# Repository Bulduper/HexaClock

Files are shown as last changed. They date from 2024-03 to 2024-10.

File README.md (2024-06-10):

# 	&#11042;	 HexaClock
<p align="center">
  
</p>

### Welcome to the repository made to share my awesome project with the world.

The *Hexa Clock* is a hexagon-shaped LED matrix with each pixel also in the shape of a hexagon!
There are 127 individual RGB pixels ready to pour some colors on your wall.

The project is based on an awesome and popular [WLED by Aircookie](https://github.com/Aircoookie/WLED) project (software-wise). I created a usermod to adjust WLED for my weirdly shaped matrix and to display the time.

All the hardware was designed, produced and assembled by me.
## 🎉Features
- Night mode - It doesn't let your eyes get tired in the night... unless you wanna throw a 🎵🕺party🕺🎵 - then better keep the night mode off, let the 🎨 colors fill the room!
- Auto-brightness - It detects the ambient light level and auto-adjusts its brightness.



- Multiple presets - the effects run one after another in a loop. To make it even more interesting they can run in random order 😀

<p float="left">
  
  
  
  
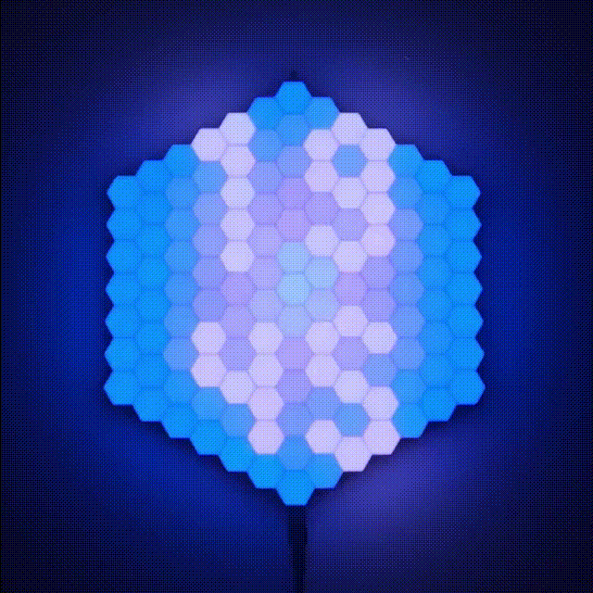
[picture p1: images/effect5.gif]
  
and more...
</p>

- Web app to control the effects
  
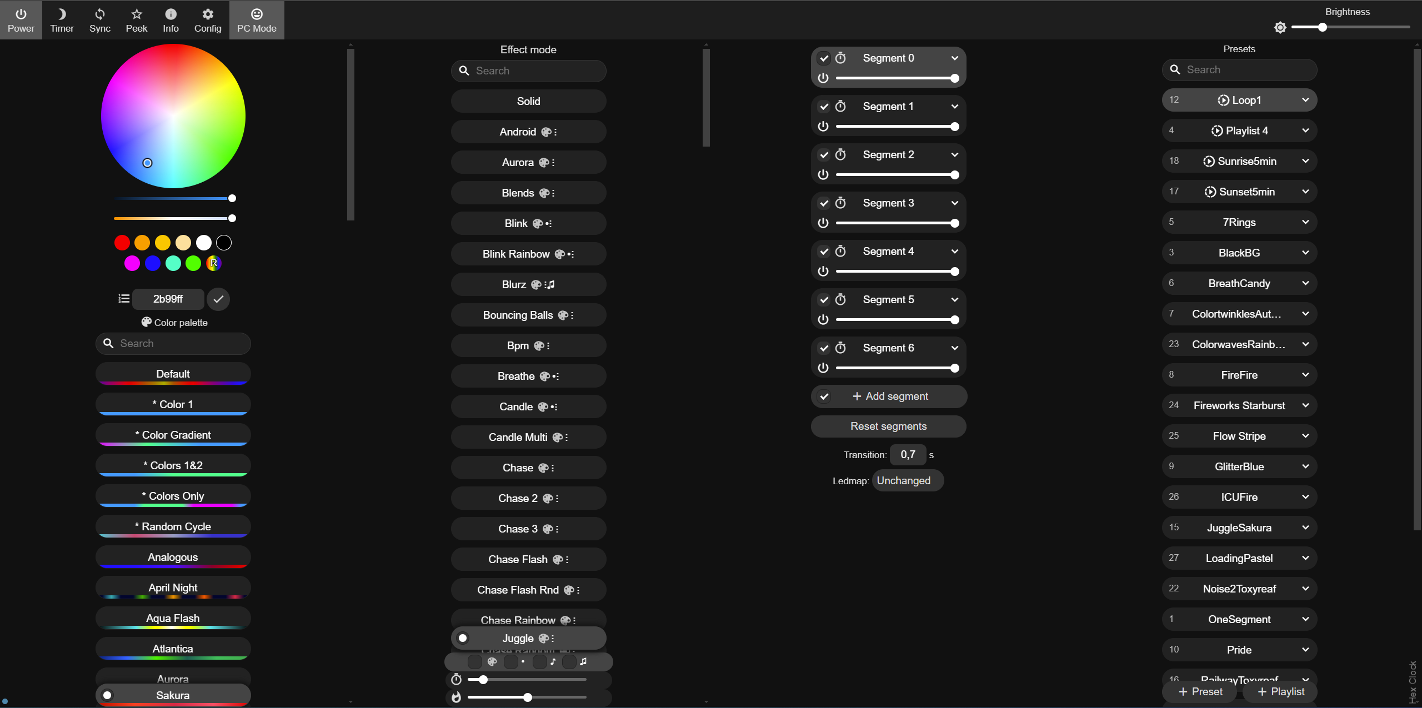
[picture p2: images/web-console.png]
  
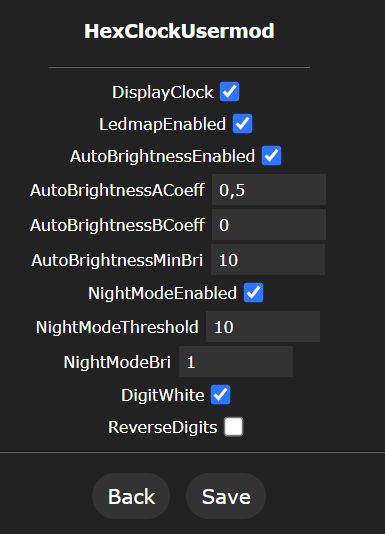
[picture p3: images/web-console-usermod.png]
  

- 🌅sunrise & sunset effects - A special effect plays

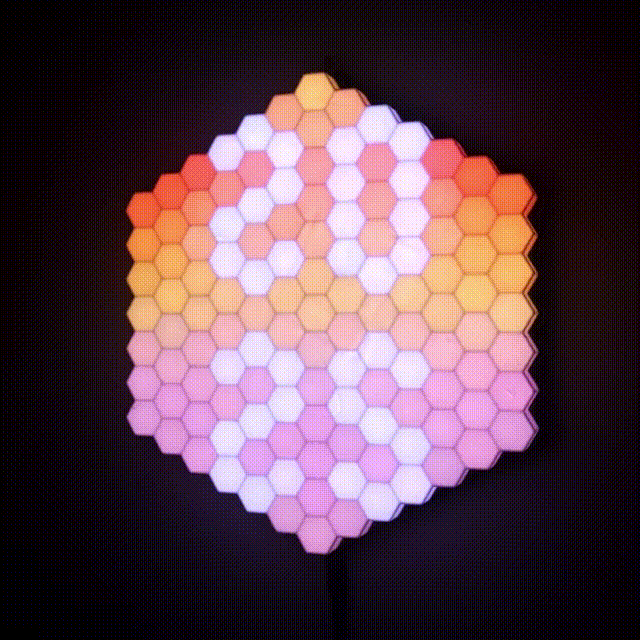
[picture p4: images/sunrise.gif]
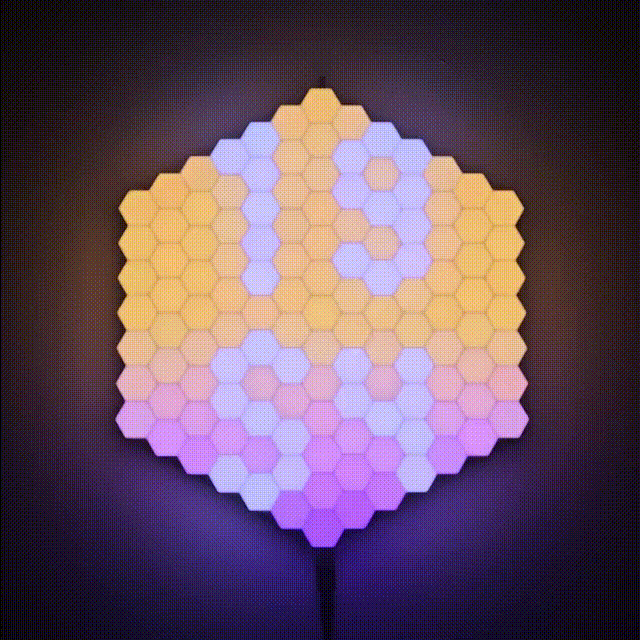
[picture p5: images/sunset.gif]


- Automatic time setting - After a boot, it takes a few seconds for the clock to know the time!



- Full control over the clock via the WLED API
## 🛠️Hardware - BOM
### 3D Printed parts
I printed all the parts with ABS. The LED strip and the PCB may get a little warm, so I was kind of hesitant to print with PLA. However I think PLA can stand such temperatures.
The front part is printed in white, all the rest in black. It looks cool. 
- HexGrid (white)
- LedBase (black)
- PcbCover (black)
- RearBase (black)
- WallHook (black)

You will find the `*.stl` files in the `/3d-model` folder.
### Electronics
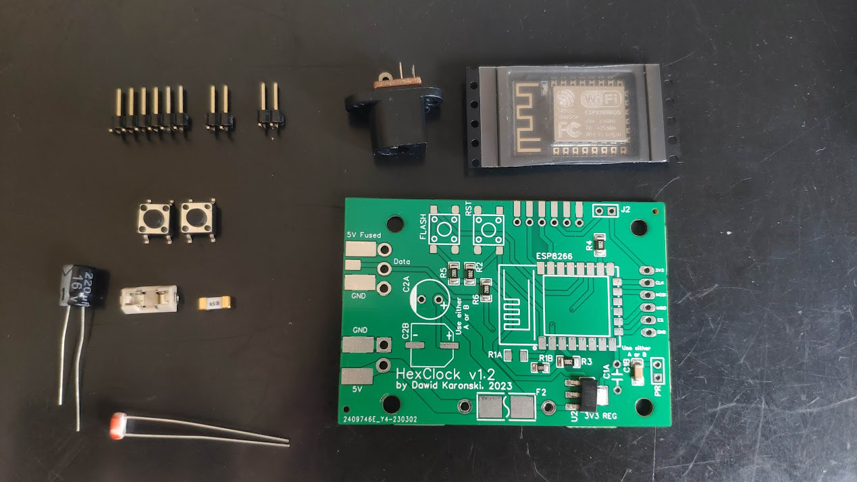
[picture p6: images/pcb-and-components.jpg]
pcb-and-components

- custom PCB
- ESP8266-12E/F [LINK](https://www.aliexpress.com/item/1005004265299852.html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) 
>*ESP32 is also supported (tested with ESP-32 devkit with WROOM-32)*
- FTDI programmer + wires
- 2x tact switch 5mm
- PR photoresistor 5537 or similar (~20-50kOhm bright resistance)
- C2A THT capacitor 220uF 16V
- F2 SMD 1808 5A fuse + fuse holder
- a bunch of 90&deg; angled 2.54mm male "dupont" pins
- J2 jumper 2.54mm
- R1B 6.8kOhm*
- R2 10kOhm*
- R3 10kOhm*
- R4 10kOhm*
- R5 10kOhm*
- R6 10kOhm*
- C1B 100nF*
- U2 AMS1117-3.3 voltage regulator*
- 5V WS2812B 60led/meter LED strip approx 2.2m long (total 127 leds)
- Power jack 5.5/2.5mm socket
- ~2m of 18AWG wire or similar
- ~1m of 26AWG wire or similar
- Power supply 5V/5A DC 5.5/2.5mm power jack
- (if needed) Power cord extension 5.5/2.5mm power jack

*presoldered on the custom PCB

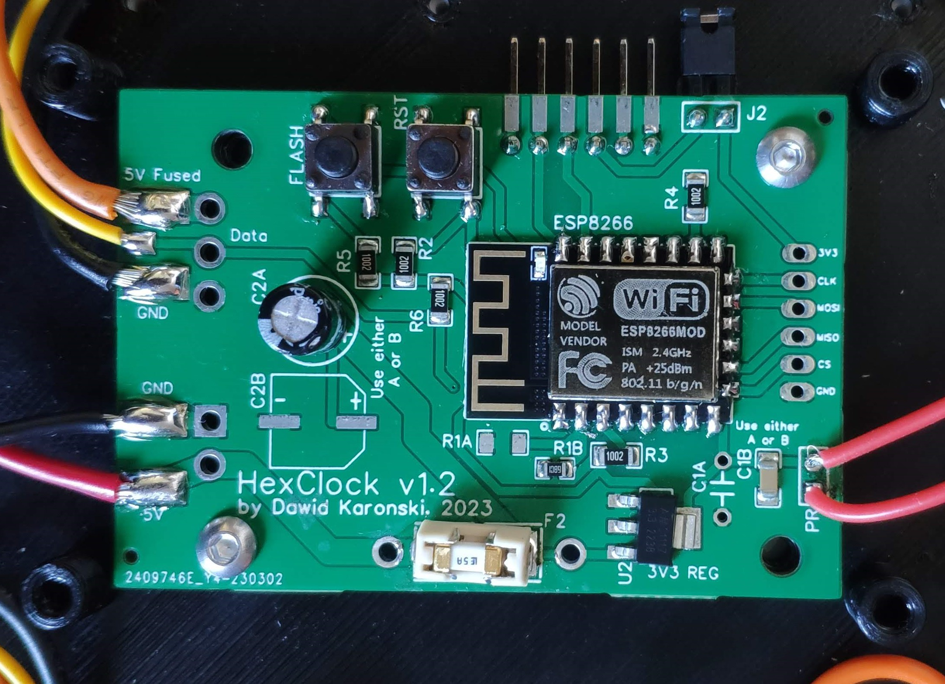
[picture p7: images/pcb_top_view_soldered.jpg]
assembled-pcb

### Screws
- M2x5 x30
- M3x8 x6
- M3x5 x4
### Tools
- 3D printer
- soldering iron with a small tip
- solder
- wire stripper
## 💻Installation

### Prerequisites
In order to compile and upload the code to your ESP, you will need [VS Code](https://code.visualstudio.com/Download) installed. You will also need [PlatformIO](https://platformio.org/platformio-ide), a VS Code extension for embedded C/C++ development.

### Setup and upload
You can clone the [WLED-HexClock](https://github.com/Bulduper/WLED-HexClock.git) repository forked from the original WLED **[recommended]**. It already includes all the necessary changes to the code. Note that the fork might not have the latest version of the core.
If you choose this method, go directly to the **step 10**.

If you prefer to work on the vanilla WLED follow all the steps:

1. Clone the original WLED by Aircoookie repository `git clone https://github.com/Aircoookie/WLED.git`.

2. Copy the `usermod_v2_hexa_clock` folder and paste into the original `WLED/usermods` folder. 

3. To `WLED/wled00/wled.h` add `WLED_GLOBAL int8_t currentLedmap _INIT(-1);` (around line 240)
```cpp
// Global Variable definitions
WLED_GLOBAL int8_t currentLedmap _INIT(-1);
WLED_GLOBAL char versionString[] _INIT(TOSTRING(WLED_VERSION));
```

4. And to `WLED/wled00/wled.cpp` add `currentLedmap = loadLedmap;` (around line 177)
```cpp
  if (loadLedmap >= 0) {
    if (!strip.deserializeMap(loadLedmap) && strip.isMatrix && loadLedmap == 0) strip.setUpMatrix();
    currentLedmap = loadLedmap;
    loadLedmap = -1;
  }
```
5. To `WLED/wled00/usermods_list.cpp` add `#ifdef USERMOD_HEXA_CLOCK
  #include "../usermods/usermod_v2_hexa_clock/usermod_v2_hexa_clock.h"
#endif` (around line 176)
```cpp
#endif

#ifdef USERMOD_HEXA_CLOCK
  #include "../usermods/usermod_v2_hexa_clock/usermod_v2_hexa_clock.h"
#endif

#if defined(WLED_USE_SD_MMC) || defined(WLED_USE_SD_SPI)
```
6. To `WLED/wled00/usermods_list.cpp` add `usermods.add(new HexaClock());` (around line 202)
```cpp
void registerUsermods()
{
/*
   * Add your usermod class name here
   * || || ||
   * \/ \/ \/
   */
  #ifdef USERMOD_HEXA_CLOCK
  usermods.add(new HexaClock());
  #endif
  //usermods.add(new MyExampleUsermod());
```
7. To `WLED/wled00/const.h` add `#define USERMOD_ID_HEXA_CLOCK             41     // Usermod Hexa-Clock` (around line 155)
```cpp
#define USERMOD_ID_STAIRWAY_WIPE         44     //Usermod "stairway-wipe-usermod-v2.h"
#define USERMOD_ID_HEXA_CLOCK            45     //Usermod Hexa-Clock
//Access point behavior
```
8. Comment out line 14 in `WLED/platform.ini`. **Make sure that all `default_envs` are commented out in the main platformio.ini file**.
```ini
# CI binaries
;; default_envs = nodemcuv2, esp8266_2m, esp01_1m_full, esp32dev, esp32_eth # ESP32 variant builds are temporarily excluded from CI due to toolchain issues on the GitHub Actions Linux environment
;default_envs = nodemcuv2, esp8266_2m, esp01_1m_full, esp32dev, esp32_eth, lolin_s2_mini, esp32c3dev, esp32s3dev_8MB
```
9. Copy the `usermod_v2_hexa_clock/platformio_override.ini` file into the main `WLED` folder (next to `WLED/platformio.ini`).
10. Choose your board in `platformio_override.ini`
```toml
[platformio]
# Choose depending on your board type (ESP8266 or ESP32)
default_envs = HexaClock_ESP8266
; default_envs = HexaClock_ESP32
```
11. Make sure that the power supply is disconnected
12. Connect the jumper
13. \* Connect the FTDI programmer to your PC via USB cable and to the ESP via PCB pins.
14. \* Press both RST and FLASH simultaneously, then release RST, then release FLASH buttons. This will make the board enter flash mode.
15. Upload the code to ESP
16. After the upload is done, disconnect the jumper and the FTDI programmer

\* Required for non-dev boards only

## 1️⃣First run
0. Power up the clock
1. Connect to `HexaClock-AP` wifi access point using your smartphone or PC
2. Go to `4.3.2.1` (default ip address) in your browser
3. If you see the WLED dashboard, go to `4.3.2.1/edit` 
4. For each of the following files in the `/config` folder: `cfg.json`, `ledmap.json`, `ledmap1.json`, `presets.json` - click `Choose file and upload`. At the end of the operation you should have 4 files uploaded to `/edit` path.
5. Configure your HexaClock to connect to your existing network
6. [Optional] Specify a friendly mDNS address e.g. http://hexa-clock.local
7. Click Save & connect
8. Connect back to your local WiFi network on our PC
9. Go to the mDNS address you've specified. If the mDNS address does not resolve, scan your network (e.g. using AngryIP Scanner) to discover the IP address of your HexaClock.

## 📈Improvements for the future
- Design "shape-aware" effects. Using the 2D, hexagonal matrix gives opportunities for very cool (much cooler than the current) effects.
- Design the PCB in the same shape and size as the display, so that it's also a base. All the electronics components would be placed on in (including the LEDs, power connector and light sensor). It would make the assembly much easier.
- Use ESP-32 - the modern, more powerful and more reliable board.

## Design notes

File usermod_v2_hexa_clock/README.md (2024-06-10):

### Other modifications
To `wled.h` add `WLED_GLOBAL int8_t currentLedmap _INIT(-1);` (line 240)

And to `wled.cpp` add `currentLedmap = loadLedmap;` (line 177)

Copy `platformio_override.ini` to the main folder (next to `platformio.ini`) and choose your board.

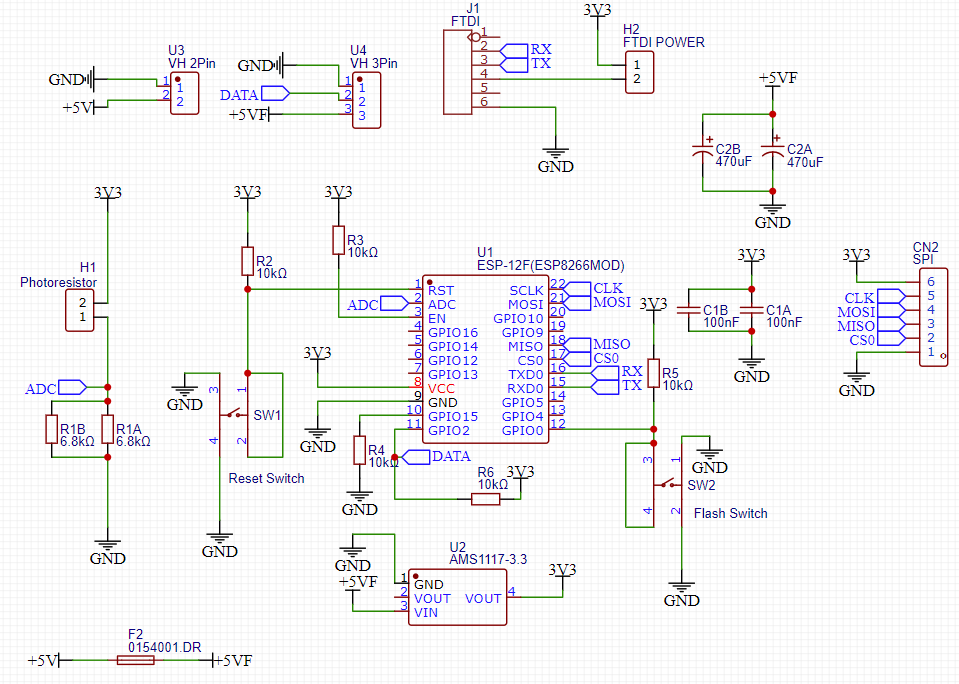
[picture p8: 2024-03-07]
images/pcb-schematic.png

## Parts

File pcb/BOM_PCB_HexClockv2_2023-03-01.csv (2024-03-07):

ID | Name | Designator | Footprint | Quantity | Manufacturer Part | Manufacturer | Supplier | Supplier Part | Price
1 | 0154001.DR | F2 | FUSE-SMD_L9.8-W5.1 | 1 | 0154001.DR | Littelfuse(美国力特) | LCSC | C206908 | 0.215
2 | Photoresistor | PR | HDR-F-2.54_1X2 | 1 |  |  | LCSC | C49661 | 0.006
3 | Reset Switch | RST | KEY-SMD_4P-L6.2-W6.2-P4.50-LS9.2-1 | 1 | 6*6*12SMD Tactile Switch | ValuePro | LCSC | C66637
4 | Flash Switch | FLASH | KEY-SMD_4P-L6.2-W6.2-P4.50-LS9.2-1 | 1 | 6*6*12SMD Tactile Switch | ValuePro | LCSC | C66637
5 | ESP-12F(ESP8266MOD) | ESP8266 | WIFIM-SMD_ESP-12F-ESP8266MOD | 1 | ESP-12F(ESP8266MOD) | Ai-Thinker | LCSC | C82891 | 0.352
6 | 6.8kΩ | R1B | R0805 | 1 | 0805W8F6801T5E | UNI-ROYAL(厚声) | LCSC | C17772
7 | AMS1117-3.3 | U2 | SOT-223-3_L6.5-W3.4-P2.30-LS7.0-BR | 1 | AMS1117-3.3 | AMS | LCSC | C6186 | 0.025
8 | 6.8kΩ | R1A | R1206 | 1 | CR1206J40682G | LIZ | LCSC | C102380 | 0.001
9 | 100nF | C1A | CAP-TH_L5.0-W2.5-P5.08-D0.7 | 1 | CS1-F6Y5V2B104ZSPW | Guangdong Fenghua Advanced Tech | LCSC | C277965 | 0.003
10 | 100nF | C1B | C1206 | 1 | CL31B104KBCNNNC | SAMSUNG(三星) | LCSC | C24497 | 0.002
11 | 470uF | C2A | CAP-TH_BD8.0-P3.50-D0.6-FD | 1 | EWH1CM471F120T | AISHI | LCSC | C105314 | 0.007
12 | 470uF | C2B | CAP-SMD_BD8.1-L8.3-W8.3-LS9.3-FD | 1 | XT470UF16V90RV0085 | KNSCHA(科尼盛) | LCSC | C2992615 | 0.013
13 | FTDI POWER | J2 | HDR-F-2.54_1X2 | 1 |  |  | LCSC | C49661 | 0.006
14 | FTDI | J1 | HEADER-1X6-SMD-MALE-2.54-90 | 1 | P125-1106A0BZYB1
15 | 10kΩ | R2,R3,R4,R5,R6 | R1206 | 5 | 1206W4F1002T5E | UNI-ROYAL(厚声) | LCSC | C17902

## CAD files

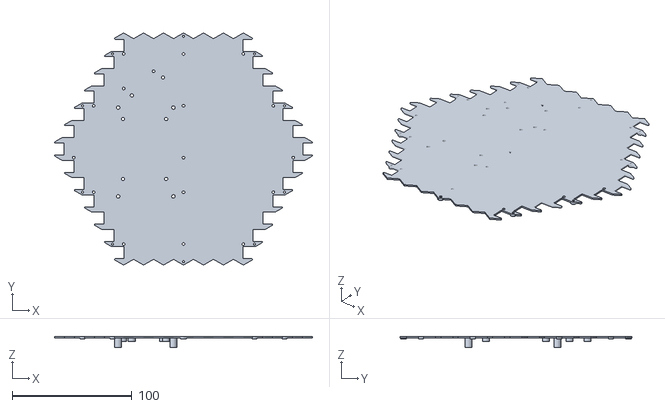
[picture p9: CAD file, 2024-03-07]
3d-model/LedBase_v2.stl
215.4 x 193.8 x 9.20

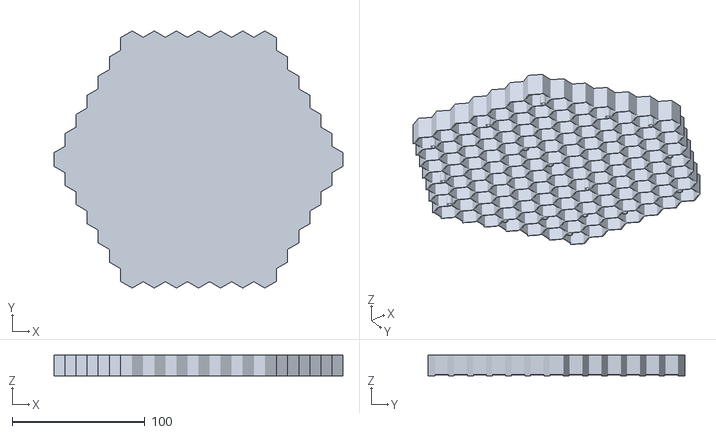
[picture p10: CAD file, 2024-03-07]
3d-model/HexGrid_v2.stl
217.9 x 193.8 x 15.6

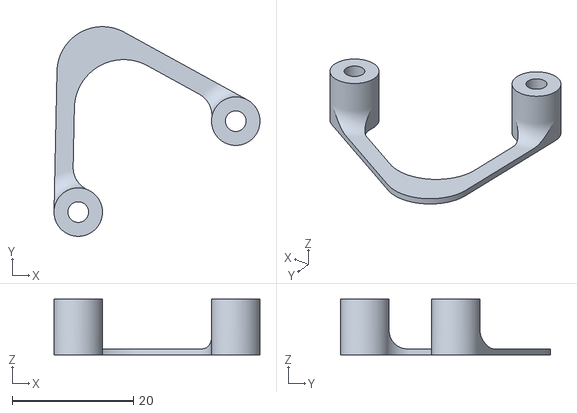
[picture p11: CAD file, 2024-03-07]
3d-model/WallHook_v2.stl
34.0 x 34.6 x 9.20

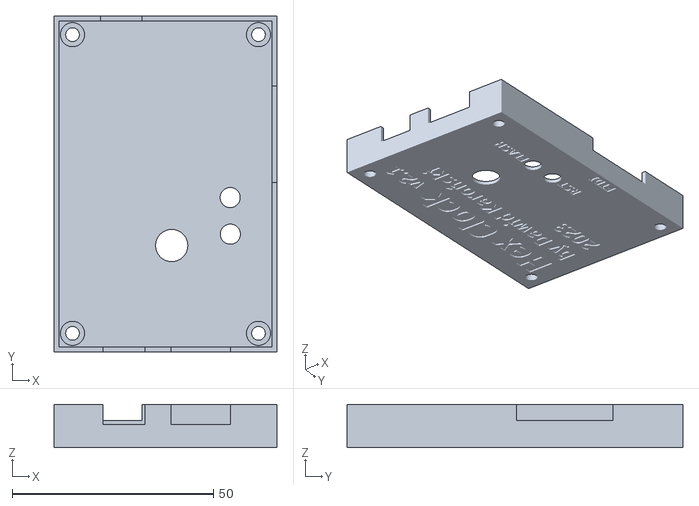
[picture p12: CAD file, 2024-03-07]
3d-model/PcbCover_v2.stl
55.4 x 83.4 x 10.7

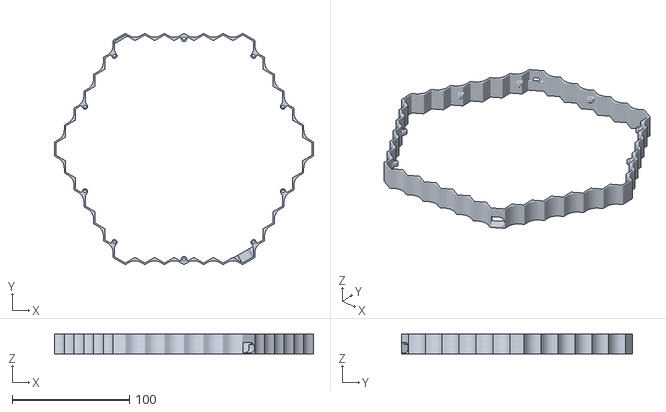
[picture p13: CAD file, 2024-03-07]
3d-model/RearBase_v2.stl
220.7 x 197.1 x 17.0

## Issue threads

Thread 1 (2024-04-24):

problema esp 32 non riesco a copiare

dipietrofilippo, 2024-04-24:
Ciao, ho un chip esp32, ma utilizzando il programma "visual studio" non riesco a programmare il chip, mi escono tanti errori e non riesco ad andare avanti.
Hai qualche soluzione?
Grazie

Bulduper, 2024-04-24:
Make sure that you have Platform.io extension installed. Follow the guide [https://kno.wled.ge/advanced/compiling-wled/](https://kno.wled.ge/advanced/compiling-wled/)

dipietrofilippo, 2024-04-25:
Purtroppo non riesco a programmare il chip con vs studio, ho provato a configurare il software “WLED HEXA CLOCK” ma, come ti ho già detto, mi escono tanti errori, ho provato a configurare il software originale “WLED” purtroppo il risultato è lo stesso.
Mi dispiace perché è un bellissimo progetto e davvero ho voglia di realizzarlo

Bulduper, 2024-04-25:
You gave practically no information about your errors. If you have issues with uploading the original WLED code, then it is not an issue with the HexaClock modification. Please try to find help on the WLED original repo, the community there is great and you will definitely find the cause. Don't forget to document your problem well!

dipietrofilippo, 2024-04-25:
Ok grazie mille, domani provo di nuovo e fornisco informazioni più dettagliate

Closed 2024-04-25.

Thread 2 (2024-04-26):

problema per caricare WLED-HexClock

dipietrofilippo, 2024-04-26:
sto provando a caricare [WLED-HexClock](https://github.com/Bulduper/WLED-HexClock.git), ma sto avendo molti problemi.
vi invio uno screenshot dell'errore che si presenta quando cerco di caricare il repository su Visual Studio Code
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

Raabensohn, 2024-05-05:
I have the same problem, what did you do?

Closed 2024-04-26.

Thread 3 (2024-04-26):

clock configuration

dipietrofilippo, 2024-04-26:
hi, I solved all the code installation problems, now I don't understand only one thing, that is, I didn't understand the last step you wrote.

If you see the WLED dashboard, go to /edit path
For each of the following files in the /config folder: cfg.json, ledmap.json, ledmap1.json, presets.json - click Choose file and upload

what should I do?

Bulduper, 2024-05-05:
Given that your local HexaClock url is http://hexa-clock.local you should visit http://hexa-clock.local/edit
You should see a file browser.
Upload all the files found here: https://github.com/Bulduper/HexaClock/tree/main/config

Bulduper, 2024-05-13:
I'm glad you did it. I am closing this issue.  @dipietrofilippo could you please share your finished clock (photos or video) on [Instructables](https://www.instructables.com/LED-Hexagon-Wall-Clock/) by clicking `I Made It` in the comment section?

dipietrofilippo, 2024-05-13:
Ciao, un ultima domanda, ho usato un chip esp32 , non sono riuscito a trovare il pin per inserire il fotoresistore, che consiglio mi puoi dare?

Closed 2024-05-13.

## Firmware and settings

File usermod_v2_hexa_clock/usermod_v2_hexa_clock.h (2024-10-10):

#pragma once

#include "wled.h"
#include "digits.h"

#define PHOTORESISTOR_PIN A0
#define LEDS_NO 127

// the frequency to check photoresistor, 1 seconds
#ifndef USERMOD_SN_PHOTORESISTOR_MEASUREMENT_INTERVAL
#define USERMOD_SN_PHOTORESISTOR_MEASUREMENT_INTERVAL 1000
#endif

// how many seconds after boot to take first measurement, 1 seconds
#ifndef USERMOD_SN_PHOTORESISTOR_FIRST_MEASUREMENT_AT
#define USERMOD_SN_PHOTORESISTOR_FIRST_MEASUREMENT_AT 1000
#endif

// supplied voltage
#ifndef USERMOD_SN_PHOTORESISTOR_REFERENCE_VOLTAGE
#define USERMOD_SN_PHOTORESISTOR_REFERENCE_VOLTAGE 1
#endif

// 10 bits
#ifndef USERMOD_SN_PHOTORESISTOR_ADC_PRECISION
#define USERMOD_SN_PHOTORESISTOR_ADC_PRECISION 1024.0f
#endif

// resistor size 10K hms
#ifndef USERMOD_SN_PHOTORESISTOR_RESISTOR_VALUE
#define USERMOD_SN_PHOTORESISTOR_RESISTOR_VALUE 6800.0f
#endif

// only report if differance grater than offset value
#ifndef USERMOD_SN_PHOTORESISTOR_OFFSET_VALUE
#define USERMOD_SN_PHOTORESISTOR_OFFSET_VALUE 5
#endif
/*
 * Usermods allow you to add own functionality to WLED more easily
 * See: https://github.com/Aircoookie/WLED/wiki/Add-own-functionality
 * 
 * This is an example for a v2 usermod.
 * v2 usermods are class inheritance based and can (but don't have to) implement more functions, each of them is shown in this example.
 * Multiple v2 usermods can be added to one compilation easily.
 * 
 * Creating a usermod:
 * This file serves as an example. If you want to create a usermod, it is recommended to use usermod_v2_empty.h from the usermods folder as a template.
 * Please remember to rename the class and file to a descriptive name.
 * You may also use multiple .h and .cpp files.
 * 
 * Using a usermod:
 * 1. Copy the usermod into the sketch folder (same folder as wled00.ino)
 * 2. Register the usermod by adding #include "usermod_filename.h" in the top and registerUsermod(new MyUsermodClass()) in the bottom of usermods_list.cpp
 */

//class name. Use something descriptive and leave the ": public Usermod" part :)
class HexaClock : public Usermod {
  private:

  float referenceVoltage = USERMOD_SN_PHOTORESISTOR_REFERENCE_VOLTAGE;
  float resistorValue = USERMOD_SN_PHOTORESISTOR_RESISTOR_VALUE;
  float adcPrecision = USERMOD_SN_PHOTORESISTOR_ADC_PRECISION;
  int8_t offset = USERMOD_SN_PHOTORESISTOR_OFFSET_VALUE;

  unsigned long readingInterval = USERMOD_SN_PHOTORESISTOR_MEASUREMENT_INTERVAL;
  // set last reading as "40 sec before boot", so first reading is taken after 20 sec
  unsigned long lastMeasurement = UINT32_MAX - (USERMOD_SN_PHOTORESISTOR_MEASUREMENT_INTERVAL - USERMOD_SN_PHOTORESISTOR_FIRST_MEASUREMENT_AT);
  // flag to indicate we have finished the first getTemperature call
  // allows this library to report to the user how long until the first
  // measurement
  bool getLuminanceComplete = false;
  uint16_t lastLuminance = 0;

    //Private class members. You can declare variables and functions only accessible to your usermod here
    unsigned long lastTime = 0;

    // set your config variables to their boot default value (this can also be done in readFromConfig() or a constructor if you prefer)
    bool displayClock = true;
    bool ledmapEnabled = true;
    uint8_t reverseRoundMap[LEDS_NO];
    uint8_t reverseVerticalMap[LEDS_NO];
    bool autoBrightnessEnabled = true;
    float autoBrightnessACoeff = 0.5;
    float autoBrightnessBCoeff = 0.0;
    byte autoBrightnessMinBri = 10;
    bool powerOn = true;
    bool nightModeEnabled = true;
    bool nightModeOn = false;
    uint16_t nightModeThreshold = 10;
    byte nightModeBri = 1;
    
    bool digitWhite = true;
    bool reverseDigits = false;

    byte prevPreset;
    int16_t prevPlaylist;

    // These config variables have defaults set inside readFromConfig()

    int hours = 0, minutes = 0;

    uint16_t getLuminance()
    {
      // http://forum.arduino.cc/index.php?topic=37555.0
      // https://forum.arduino.cc/index.php?topic=185158.0
      float volts = analogRead(PHOTORESISTOR_PIN) * (referenceVoltage / adcPrecision);
      float amps = volts / resistorValue;
      float lux = amps * 1000000 * 2.0;
      lastLuminance = uint16_t(lux);

      lastMeasurement = millis();
      getLuminanceComplete = true;
      return uint16_t(lux);
    }

  public:
    //Functions called by WLED

    /*
     * setup() is called once at boot. WiFi is not yet connected at this point.
     * You can use it to initialize variables, sensors or similar.
     */
    void setup() {
      Serial.println("Hello from hexa_clock usermod!");

      for(int i=0; i<LEDS_NO; i++)
      {
        reverseRoundMap[roundMap[i]] = i;
        reverseVerticalMap[verticalMap[i]] = i;
      }
      // set pinmode
      pinMode(PHOTORESISTOR_PIN, INPUT);
    }


    /*
     * connected() is called every time the WiFi is (re)connected
     * Use it to initialize network interfaces
     */
    void connected() {
      Serial.println("Connected to WiFi!");
    }


    /*
     * loop() is called continuously. Here you can check for events, read sensors, etc.
     * 
     * Tips:
     * 1. You can use "if (WLED_CONNECTED)" to check for a successful network connection.
     *    Additionally, "if (WLED_MQTT_CONNECTED)" is available to check for a connection to an MQTT broker.
     * 
     * 2. Try to avoid using the delay() function. NEVER use delays longer than 10 milliseconds.
     *    Instead, use a timer check as shown here.
     */
    void loop() {
      if (millis() - lastTime > 1000) {
        if(autoBrightnessEnabled && powerOn)
        {
          uint16_t lux = getLuminance();
          
          if(lux < nightModeThreshold && nightModeEnabled)
          {
            if(!nightModeOn)
            {
              nightModeOn = true;
              prevPreset = currentPreset;
              
              prevPlaylist = currentPlaylist;
              currentPlaylist = -1;
              //apply black background
              if(!reverseDigits) applyPreset(3);
            }
            
            bri = nightModeBri;
          }
          else {
            if(nightModeOn)
            {
              nightModeOn = false;
              //if there was a playlist playing on play it again
              if(prevPlaylist != -1)
              {
                currentPlaylist = prevPlaylist;
              }
              else 
              {
                applyPreset(prevPreset);
              }
            }
            bri = constrain(lux * autoBrightnessACoeff + autoBrightnessBCoeff,autoBrightnessMinBri,255);

          }
          colorUpdated(CALL_MODE_BUTTON);
          updateInterfaces(CALL_MODE_BUTTON);
        }

        
        hours = hour(localTime);
        minutes = minute(localTime);
        lastTime = millis();
      }
    }
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
